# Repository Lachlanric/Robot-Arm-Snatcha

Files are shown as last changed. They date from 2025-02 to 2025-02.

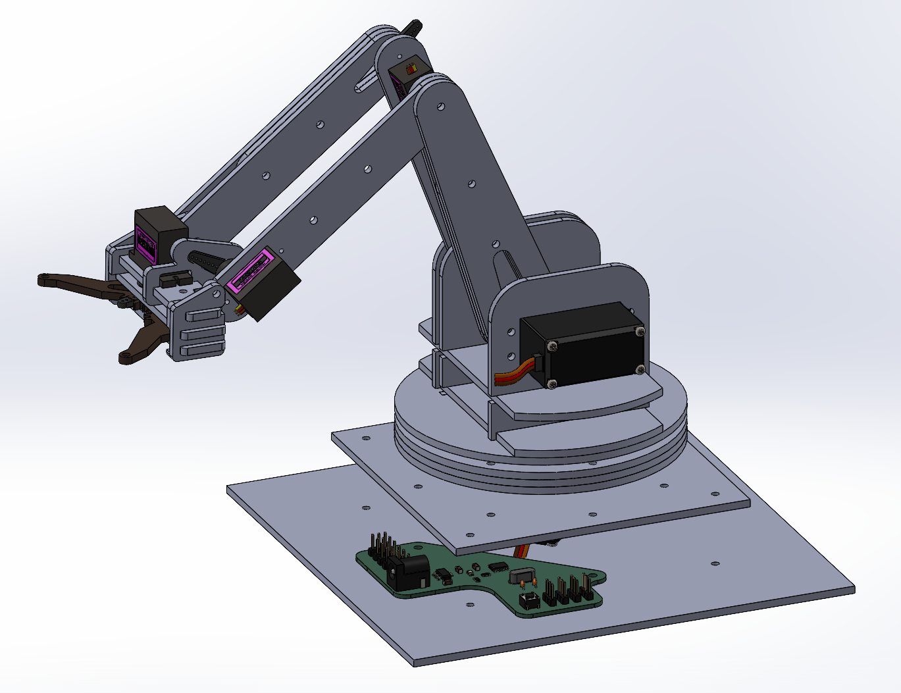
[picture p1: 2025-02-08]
Gallery/Solidworks.png

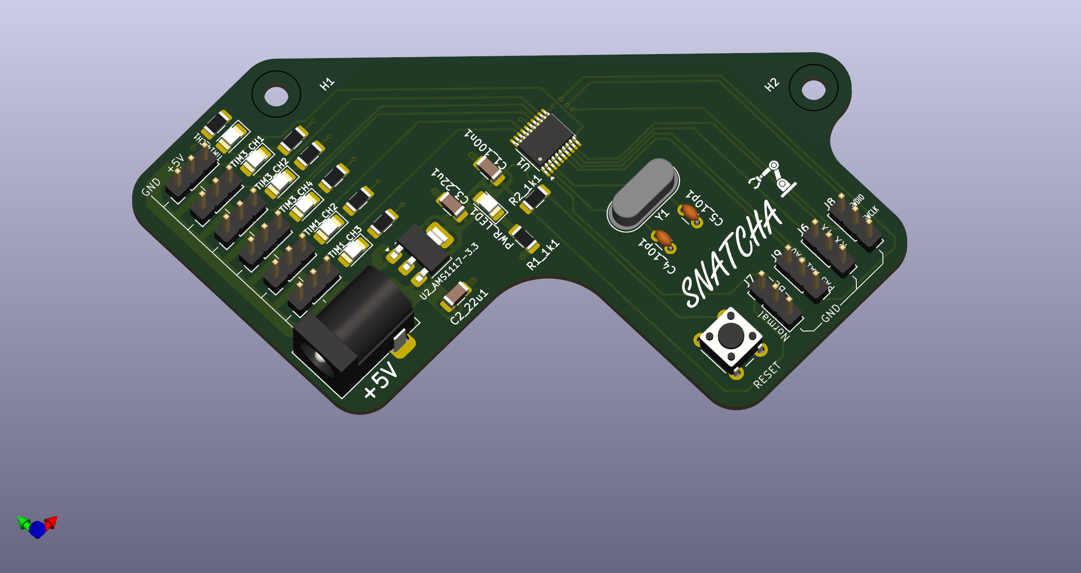
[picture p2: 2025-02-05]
Gallery/PCB.png

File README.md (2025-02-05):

# "Snatcha"

4-DoF Robotic Arm (excluding end effector) + Claw Gripper.

Entire robot (minus electronics) can be laser cut from 3mm wood or acrylic and fastened with M3 screws.

Can be controlled over UART communication (requires USB to UART converter) using either:
1. IK pose control python app `Operation/IK Control/app.py`
   
   OR
2. Oculus Quest 2 controller unity app `Operation/VR Control/Unity`

https://github.com/user-attachments/assets/1d7107a9-4986-4063-b4a9-3a9e8fb0a1fe

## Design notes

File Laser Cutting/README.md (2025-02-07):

# Laser cutting files

Cut in order of colours: Red > Cyan > Black.

Target material thickness: 3mm

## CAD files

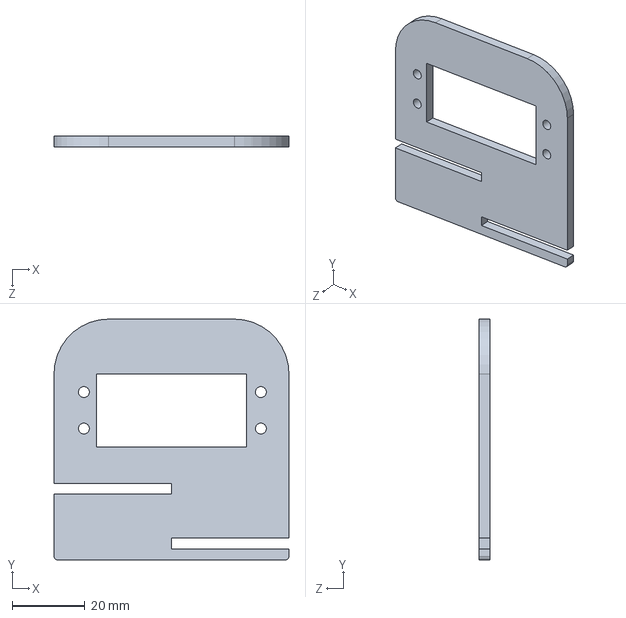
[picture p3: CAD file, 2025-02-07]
3D/SOLIDWORKS/BaseMotorSlot.SLDPRT
64.4 x 66.0 x 3.00 mm

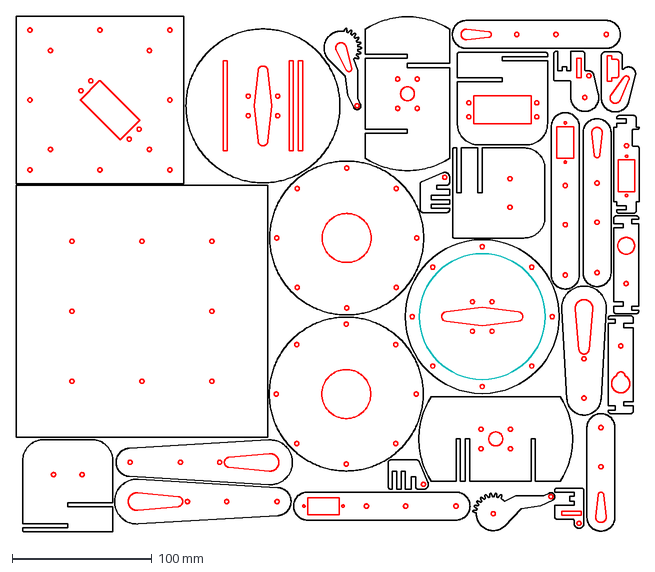
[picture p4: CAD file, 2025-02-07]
Laser Cutting/laser_cutting_colour.dxf
445.2 x 368.7 mm

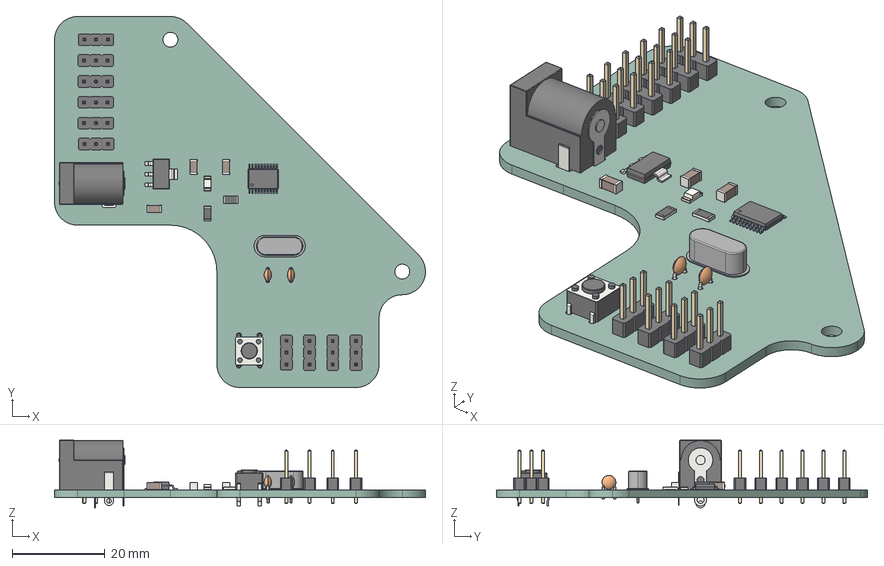
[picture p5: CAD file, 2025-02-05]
PCB/KiCad/STM32F070F6P6-Robot-Arm-2/STM32F070F6P6-Robot-Arm-2.step
80.0 x 80.0 x 14.6 mm
PinHeader_1x03_P254mm_Vertical x 10
BarrelJack_Horizontal
Crystal_HC49-4H_Vertical
R_1206_3216Metric x 2
C_1206_3216Metric x 3
LED_1206_3216Metric
C_Disc_D30mm_W16mm_P250mm x 2
SW_PUSH_6mm
SOT_223
TSSOP_20_44x65mm_P065mm
STM32F070F6P6-Robot-Arm-2_PCB

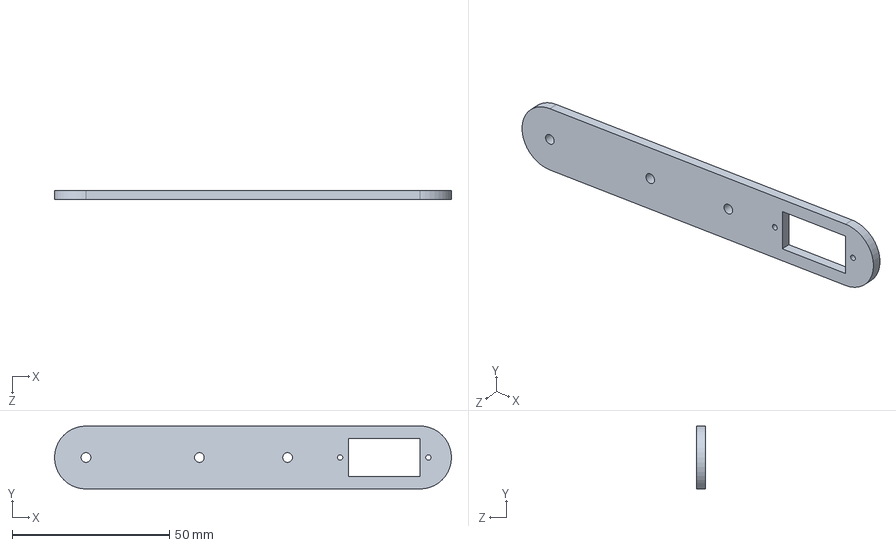
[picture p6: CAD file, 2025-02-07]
3D/SOLIDWORKS/L1_body - motor mount.SLDPRT
126.0 x 20.0 x 3.00 mm

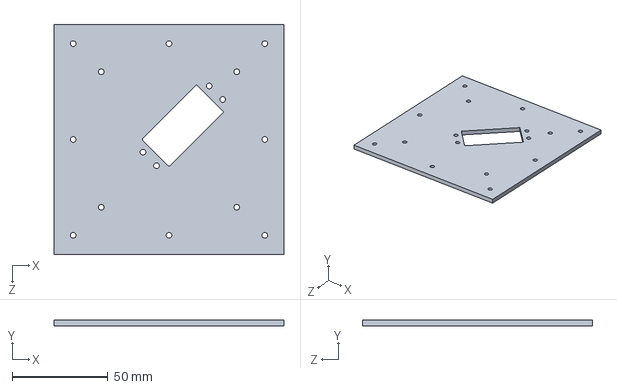
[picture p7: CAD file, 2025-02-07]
3D/SOLIDWORKS/BaseSquare.SLDPRT
120.0 x 3.00 x 120.0 mm

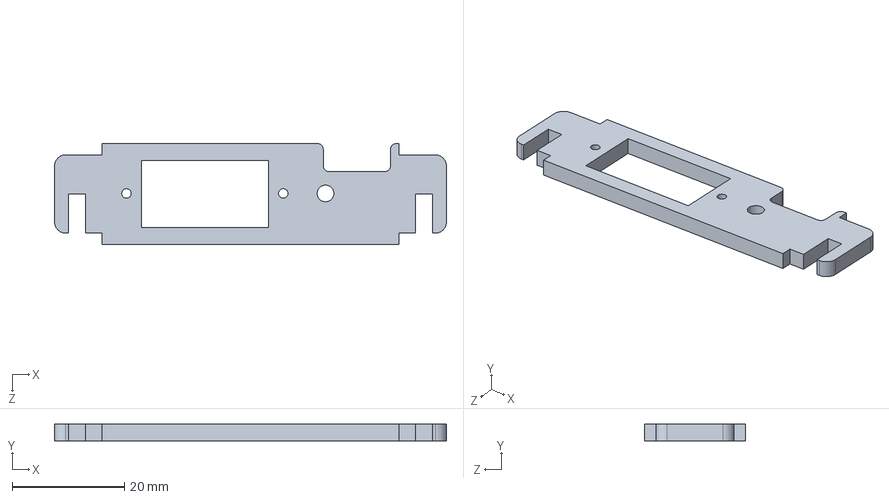
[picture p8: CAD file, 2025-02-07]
3D/SOLIDWORKS/Claw_MotorSlot.SLDPRT
70.0 x 3.00 x 18.0 mm

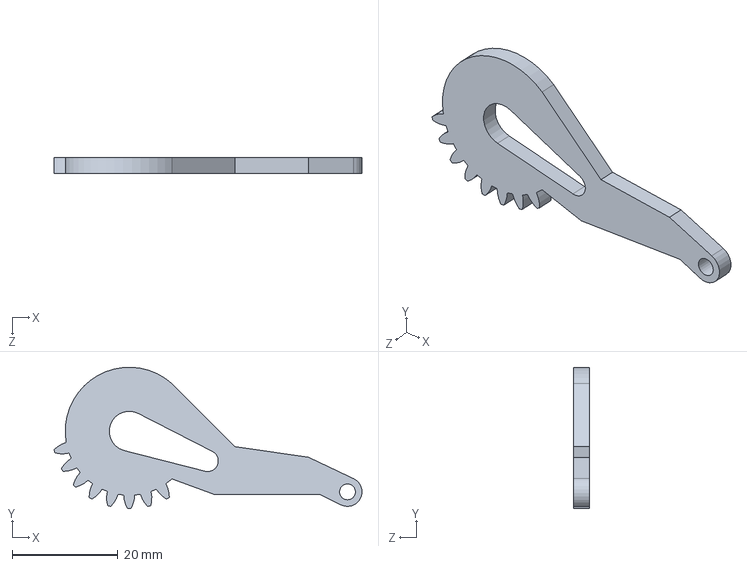
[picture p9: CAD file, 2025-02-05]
3D/SOLIDWORKS/Gear1.SLDPRT
58.2 x 26.7 x 3.00 mm

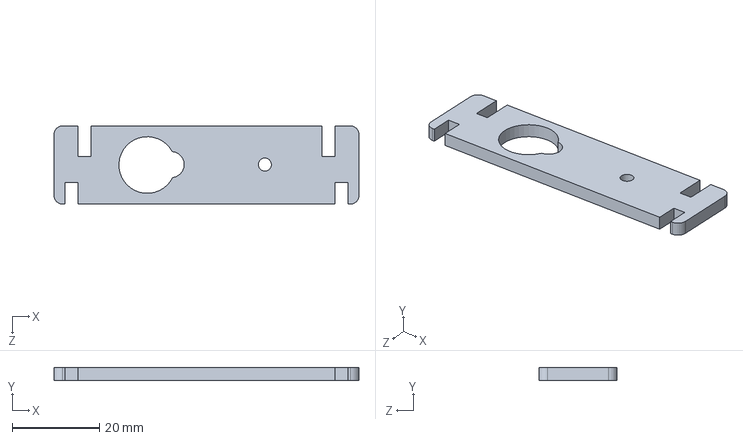
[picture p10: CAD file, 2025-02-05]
3D/SOLIDWORKS/Claw_GearSlot.SLDPRT
70.0 x 3.00 x 18.0 mm

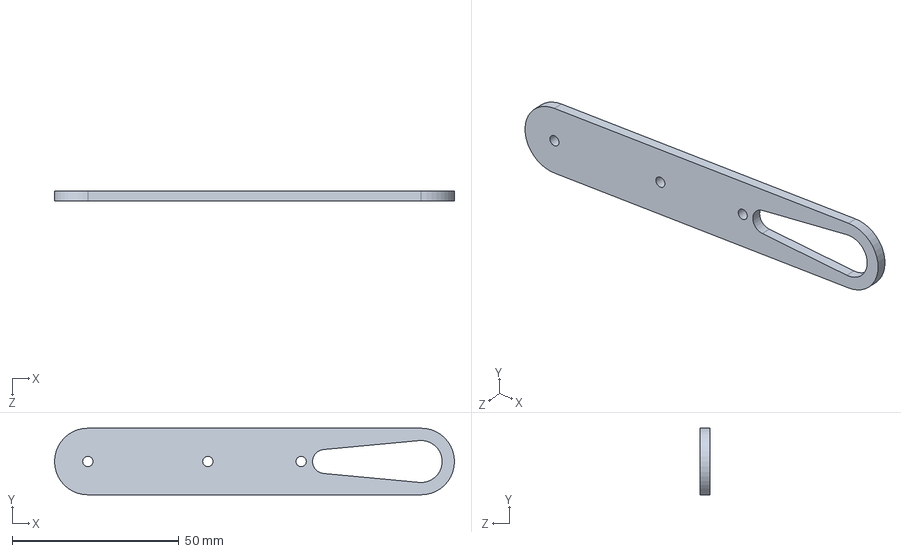
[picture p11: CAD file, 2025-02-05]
3D/SOLIDWORKS/L1_body - mg995r.SLDPRT
120.0 x 20.0 x 3.00 mm

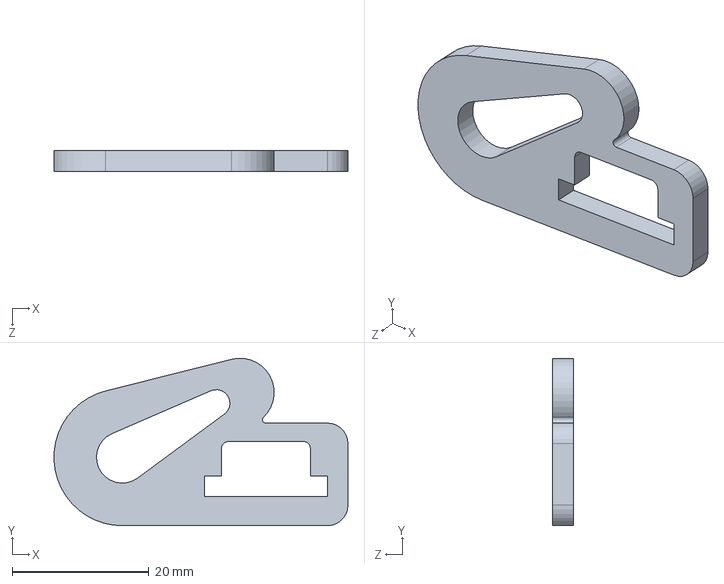
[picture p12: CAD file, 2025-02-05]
3D/SOLIDWORKS/Claw_SidePanel_Short.SLDPRT
43.0 x 24.5 x 3.00 mm

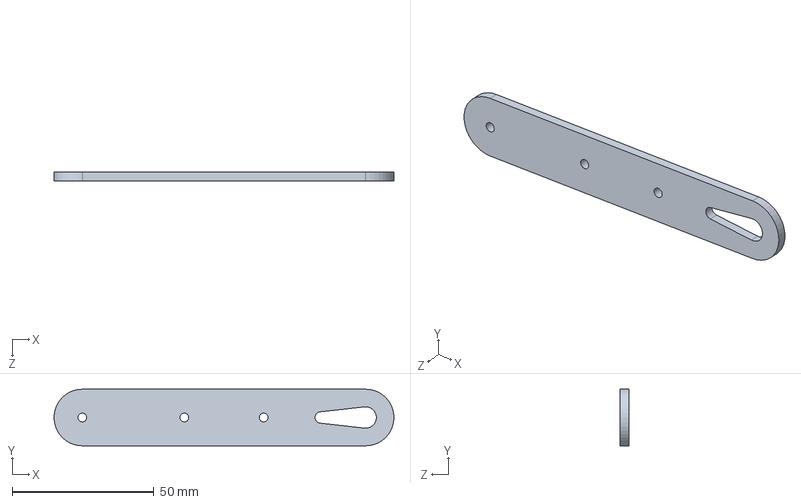
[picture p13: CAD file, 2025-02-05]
3D/SOLIDWORKS/L1_body.SLDPRT
120.0 x 20.0 x 3.00 mm

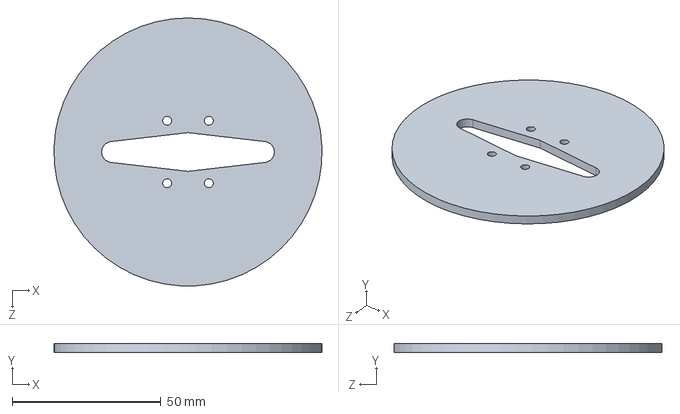
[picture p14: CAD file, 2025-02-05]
3D/SOLIDWORKS/CircleBase-InnerBottom.SLDPRT
90.0 x 3.00 x 90.0 mm

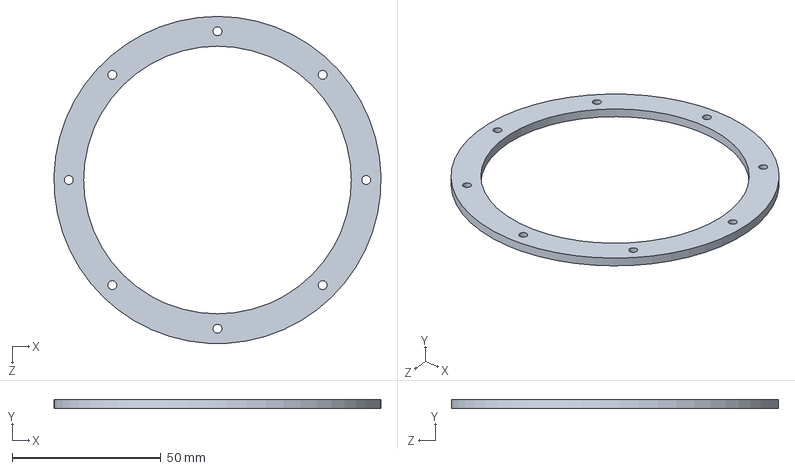
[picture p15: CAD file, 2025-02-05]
3D/SOLIDWORKS/CircleBase-OuterBottom - 2.SLDPRT
110.0 x 3.00 x 110.0 mm

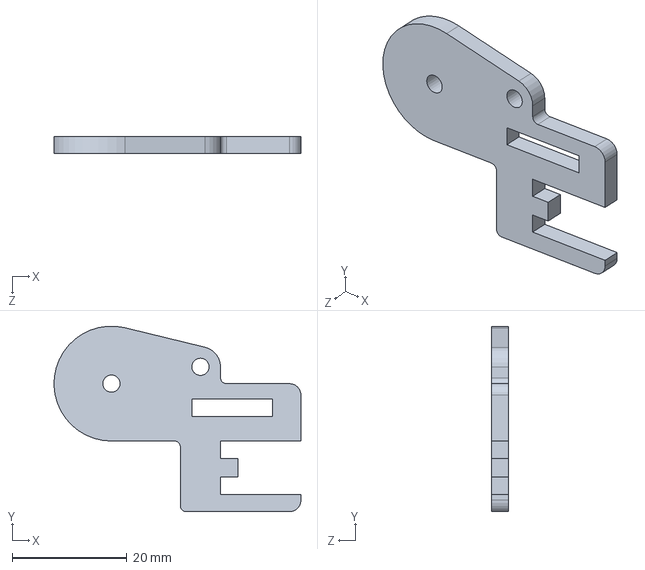
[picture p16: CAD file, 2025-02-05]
3D/SOLIDWORKS/Claw_SidePanel.SLDPRT
43.0 x 32.3 x 3.00 mm

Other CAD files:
3D/SOLIDWORKS/Assem1.SLDASM
3D/SOLIDWORKS/Claw_SidePanel_Shorter - Lock.SLDPRT
3D/SOLIDWORKS/BaseSquare - larger_2.SLDPRT
3D/SOLIDWORKS/BaseHorizontalSlots.SLDPRT
3D/SOLIDWORKS/BaseHorizontalSlots_LastInsert.SLDPRT
3D/SOLIDWORKS/BaseMotorSlot_SingleHole.SLDPRT
3D/SOLIDWORKS/BaseMotorSlot_SingleHole_LastInsert.SLDPRT
3D/SOLIDWORKS/CircleBase - UnderHorn.SLDPRT
3D/SOLIDWORKS/CircleBase-InnerTop - 3.SLDPRT
3D/SOLIDWORKS/Claw_Bottom_2.SLDPRT
3D/SOLIDWORKS/Claw_SidePanel - old.SLDPRT
3D/SOLIDWORKS/Claw_SidePanel_Shorter.SLDPRT
3D/SOLIDWORKS/Gear2.SLDPRT
3D/SOLIDWORKS/L1_body - middle spacing - mg995r taperred.SLDPRT
3D/SOLIDWORKS/L1_body - middle spacing.SLDPRT
3D/SOLIDWORKS/L1_body_taper.SLDPRT
3D/SOLIDWORKS/M90S.SLDPRT
3D/SOLIDWORKS/MG90S_horn1.SLDPRT
3D/SOLIDWORKS/MG995_large.SLDPRT

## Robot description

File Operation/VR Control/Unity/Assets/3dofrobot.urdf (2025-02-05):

<?xml version="1.0" ?>
<robot name="3dof_robot_arm">
  <!-- Base Link -->
  <link name="base_link">
    <visual>
      <geometry>
        <cylinder radius="0.1" length="0.2"/>
      </geometry>
      <origin xyz="0 0 0.1" rpy="0 0 0"/>
      <material name="grey">
        <color rgba="0.5 0.5 0.5 1"/>
      </material>
    </visual>
  </link>

  <!-- Link 1 -->
  <link name="link_1">
    <visual>
      <geometry>
        <cylinder radius="0.05" length="0.4"/>
      </geometry>
      <origin xyz="0 0 0.2" rpy="0 0 0"/>
      <material name="blue">
        <color rgba="0.0 0.0 1.0 1"/>
      </material>
    </visual>
  </link>

  <!-- Link 2 -->
  <link name="link_2">
    <visual>
      <geometry>
        <cylinder radius="0.05" length="0.4"/>
      </geometry>
      <origin xyz="0 0 0.2" rpy="0 0 0"/>
      <material name="green">
        <color rgba="0.0 1.0 0.0 1"/>
      </material>
    </visual>
  </link>

  <!-- Link 3 -->
  <link name="link_3">
    <visual>
      <geometry>
        <cylinder radius="0.05" length="0.4"/>
      </geometry>
      <origin xyz="0 0 0.2" rpy="0 0 0"/>
      <material name="red">
        <color rgba="1.0 0.0 0.0 1"/>
      </material>
    </visual>
  </link>

  <!-- Joints -->
  <!-- Joint 1 -->
  <joint name="joint_1" type="revolute">
    <parent link="base_link"/>
    <child link="link_1"/>
    <origin xyz="0 0 0.2" rpy="0 0 0"/>
    <axis xyz="0 0 1"/>
    <limit lower="-3.14" upper="3.14" effort="10" velocity="1.0"/>
  </joint>

  <!-- Joint 2 -->
  <joint name="joint_2" type="revolute">
    <parent link="link_1"/>
    <child link="link_2"/>
    <origin xyz="0 0 0.4" rpy="0 0 0"/>
    <axis xyz="0 1 0"/>
    <limit lower="-1.57" upper="1.57" effort="10" velocity="1.0"/>
  </joint>

  <!-- Joint 3 -->
  <joint name="joint_3" type="revolute">
    <parent link="link_2"/>
    <child link="link_3"/>
    <origin xyz="0 0 0.4" rpy="0 0 0"/>
    <axis xyz="1 0 0"/>
    <limit lower="-1.57" upper="1.57" effort="10" velocity="1.0"/>
  </joint>
</robot>

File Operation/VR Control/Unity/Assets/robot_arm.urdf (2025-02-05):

<?xml version="1.0"?>
<robot name="robot_arm">

  <!-- Base Link -->
  <link name="base">
    <visual>
      <geometry>
        <cylinder radius="0.05" length="0.1"/>
      </geometry>
      <origin xyz="0 0 0" rpy="0 0 0"/>
      <material name="gray">
        <color rgba="0.5 0.5 0.5 1.0"/>
      </material>
    </visual>
  </link>

  <!-- Link 1 -->
  <link name="L1">
    <visual>
      <geometry>
        <cylinder radius="0.02" length="0.1"/>
      </geometry>
      <origin xyz="0 0 0.05" rpy="0 0 0"/>
      <material name="blue">
        <color rgba="0.0 0.0 1.0 1.0"/>
      </material>
    </visual>
  </link>

  <!-- Link 2 -->
  <link name="L2">
    <visual>
      <geometry>
        <cylinder radius="0.02" length="0.1"/>
      </geometry>
      <origin xyz="0 0 0.05" rpy="0 0 0"/>
      <material name="green">
        <color rgba="0.0 1.0 0.0 1.0"/>
      </material>
    </visual>
  </link>

  <!-- End Effector -->
  <link name="end_effector">
    <visual>
      <geometry>
        <sphere radius="0.03"/>
      </geometry>
      <origin xyz="0 0 0" rpy="0 0 0"/>
      <material name="red">
        <color rgba="1.0 0.0 0.0 1.0"/>
      </material>
    </visual>
  </link>

  <!-- Base to L1 Joint -->
  <joint name="base_to_L1" type="revolute">
    <parent link="base"/>
    <child link="L1"/>
    <origin xyz="0 0 0.05" rpy="0 0 0"/>
    <axis xyz="0 0 1"/>
    <limit lower="-3.14159" upper="3.14159" effort="10" velocity="1"/>
  </joint>

  <!-- L1 to L2 Joint -->
  <joint name="L1_to_L2" type="revolute">
    <parent link="L1"/>
    <child link="L2"/>
    <origin xyz="0 0 0.1" rpy="0 0 0"/>
    <axis xyz="0 1 0"/>
    <limit lower="-3.14159" upper="3.14159" effort="10" velocity="1"/>
  </joint>

  <!-- L2 to End Effector Joint -->
  <joint name="L2_to_end_effector" type="revolute">
    <parent link="L2"/>
    <child link="end_effector"/>
    <origin xyz="0 0 0.1" rpy="0 0 0"/>
    <axis xyz="0 1 0"/>
    <limit lower="-3.14159" upper="3.14159" effort="10" velocity="1"/>
  </joint>

</robot>

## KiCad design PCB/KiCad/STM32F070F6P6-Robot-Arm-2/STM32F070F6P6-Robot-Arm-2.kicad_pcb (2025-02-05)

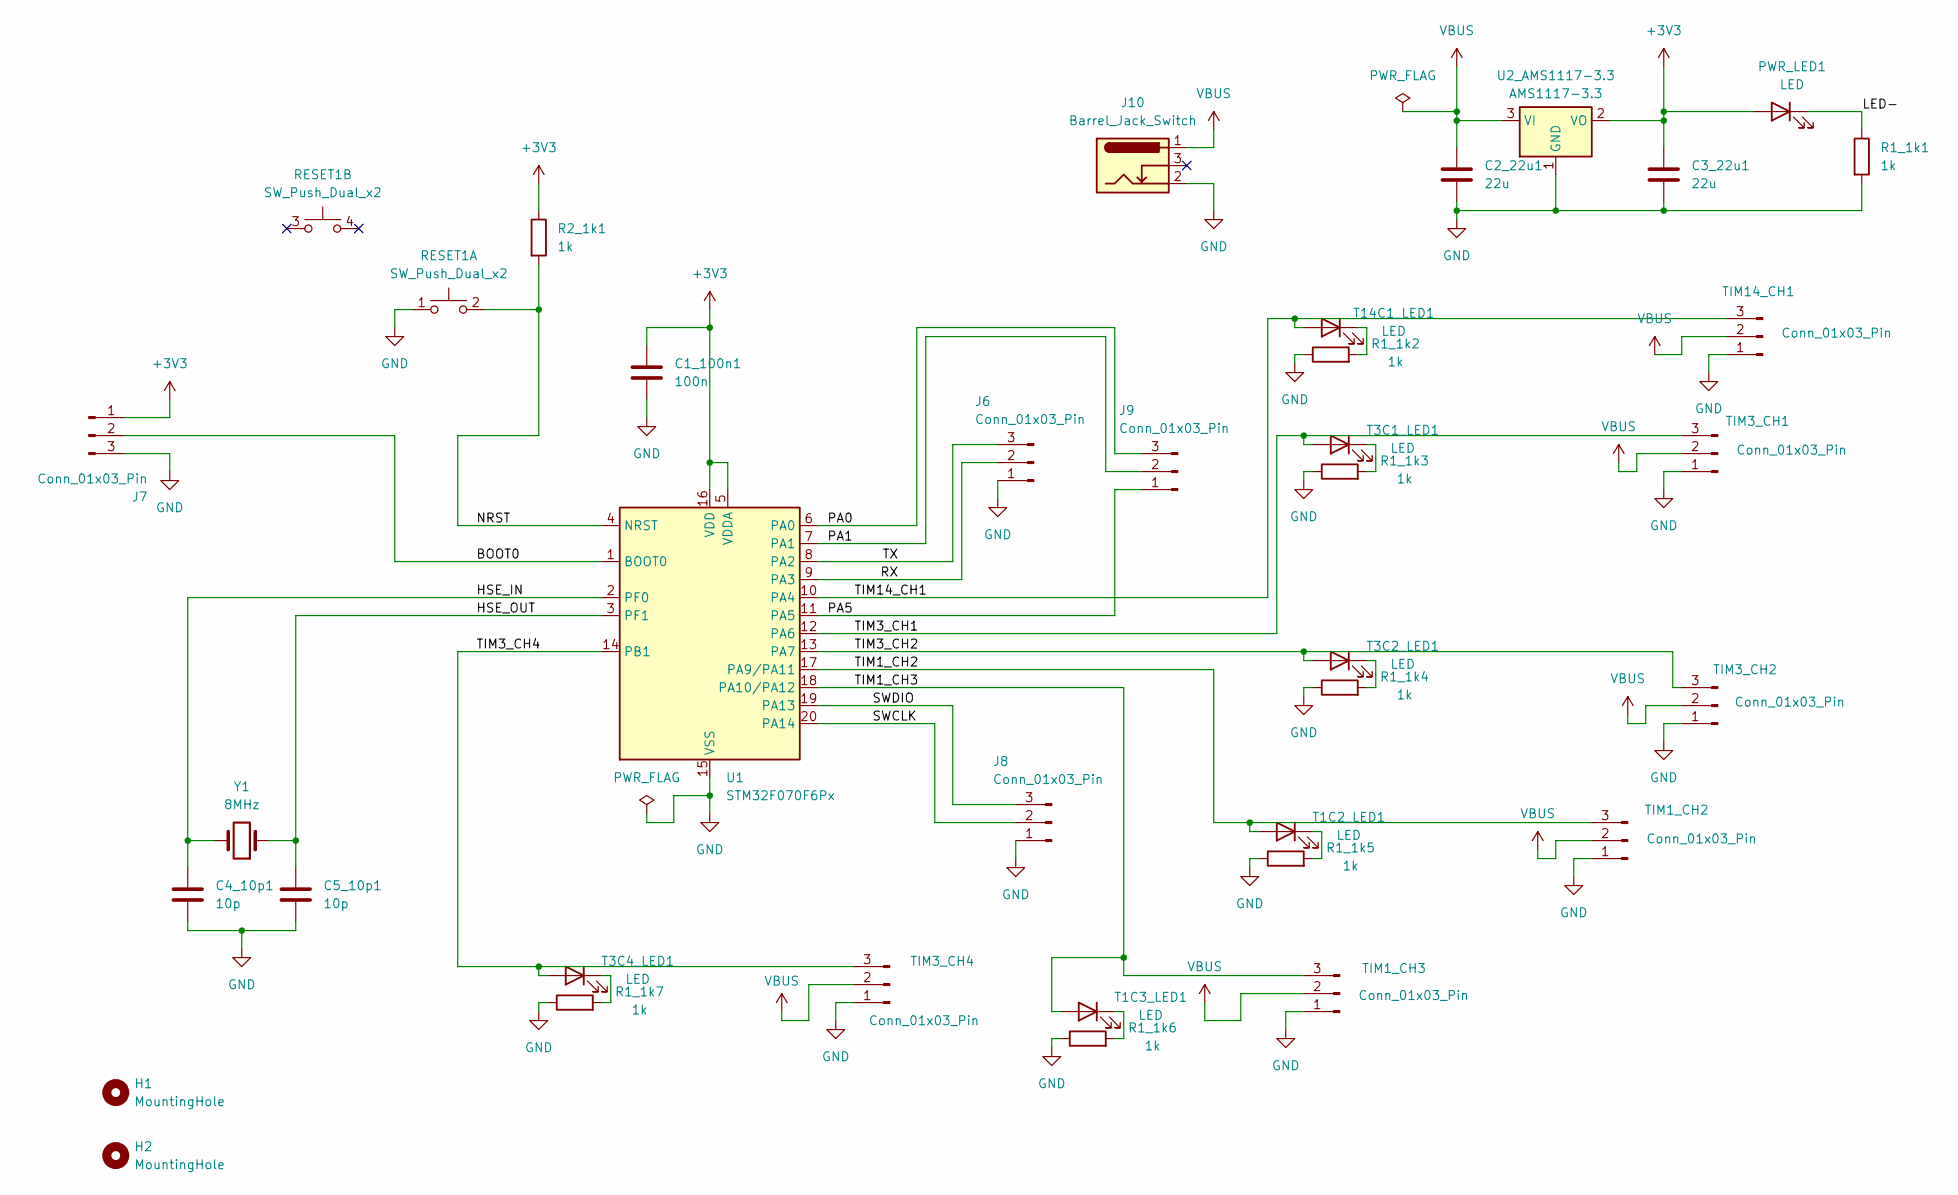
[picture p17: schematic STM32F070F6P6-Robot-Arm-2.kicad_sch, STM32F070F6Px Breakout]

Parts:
C1_100n1: 100n; C_1206_3216Metric_Pad1.33x1.80mm_HandSolder
C2_22u1, C3_22u1: 22u; C_1206_3216Metric_Pad1.33x1.80mm_HandSolder
C4_10p1, C5_10p1: 10p; C_Disc_D3.0mm_W1.6mm_P2.50mm
H1, H2: MountingHole; MountingHole_3.2mm_M3
J6, J7, J8, J9: Conn_01x03_Pin; PinHeader_1x03_P2.54mm_Vertical
J10: Barrel_Jack_Switch; BarrelJack_Horizontal
PWR_LED1: LED; LED_1206_3216Metric_Pad1.42x1.75mm_HandSolder
R1_1k1, R1_1k2, R1_1k3, R1_1k4, R1_1k5, R1_1k6, R1_1k7, R2_1k1: 1k; R_1206_3216Metric_Pad1.30x1.75mm_HandSolder
RESET1: SW_Push_Dual_x2; SW_PUSH_6mm
T1C2_LED1, T1C3_LED1, T3C1_LED1, T3C2_LED1, T3C4_LED1, T14C1_LED1: LED; LED_1206_3216Metric_Pad1.42x1.75mm_HandSolder
TIM1_CH2, TIM1_CH3, TIM3_CH1, TIM3_CH2, TIM3_CH4, TIM14_CH1: Conn_01x03_Pin; PinHeader_1x03_P2.54mm_Vertical
U1: STM32F070F6Px; TSSOP-20_4.4x6.5mm_P0.65mm
U2_AMS1117-3.3: AMS1117-3.3; SOT-223-3_TabPin2
Y1: 8MHz; Crystal_HC49-4H_Vertical

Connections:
+3V3: C1_100n1.1, C3_22u1.1, J7.1, PWR_LED1.2 (A), R2_1k1.1, U1.5 (VDDA), U1.16 (VDD), U2_AMS1117-3.3.2 (VO)
/BOOT0: J7.2, U1.1 (BOOT0)
/HSE_IN: C4_10p1.1, U1.2 (PF0), Y1.2
/HSE_OUT: C5_10p1.1, U1.3 (PF1), Y1.1
/LED-: PWR_LED1.1 (K), R1_1k1.1
/NRST: R2_1k1.2, RESET1.2 (D), U1.4 (NRST)
/PA0: J9.3, U1.6 (PA0)
/PA1: J9.2, U1.7 (PA1)
/PA5: J9.1, U1.11 (PA5)
/RX: J6.2, U1.9 (PA3)
/SWCLK: J8.2, U1.20 (PA14)
/SWDIO: J8.3, U1.19 (PA13)
/TIM1_CH2: T1C2_LED1.2 (A), TIM1_CH2.3, U1.17 (PA9/PA11)
/TIM1_CH3: T1C3_LED1.2 (A), TIM1_CH3.3, U1.18 (PA10/PA12)
/TIM3_CH1: T3C1_LED1.2 (A), TIM3_CH1.3, U1.12 (PA6)
/TIM3_CH2: T3C2_LED1.2 (A), TIM3_CH2.3, U1.13 (PA7)
/TIM3_CH4: T3C4_LED1.2 (A), TIM3_CH4.3, U1.14 (PB1)
/TIM14_CH1: T14C1_LED1.2 (A), TIM14_CH1.3, U1.10 (PA4)
/TX: J6.3, U1.8 (PA2)
GND: C1_100n1.2, C2_22u1.2, C3_22u1.2, C4_10p1.2, C5_10p1.2, J6.1, J7.3, J8.1, J10.2, R1_1k1.2, R1_1k2.1, R1_1k3.1, R1_1k4.1, R1_1k5.1, R1_1k6.1, R1_1k7.1, RESET1.1 (C), TIM1_CH2.1, TIM1_CH3.1, TIM3_CH1.1, TIM3_CH2.1, TIM3_CH4.1, TIM14_CH1.1, U1.15 (VSS), U2_AMS1117-3.3.1 (GND)
unnamed: R1_1k5.2, T1C2_LED1.1 (K)
unnamed: R1_1k6.2, T1C3_LED1.1 (K)
unnamed: R1_1k3.2, T3C1_LED1.1 (K)
unnamed: R1_1k4.2, T3C2_LED1.1 (K)
unnamed: R1_1k7.2, T3C4_LED1.1 (K)
unnamed: R1_1k2.2, T14C1_LED1.1 (K)
VBUS: C2_22u1.1, J10.1, TIM1_CH2.2, TIM1_CH3.2, TIM3_CH1.2, TIM3_CH2.2, TIM3_CH4.2, TIM14_CH1.2, U2_AMS1117-3.3.3 (VI)

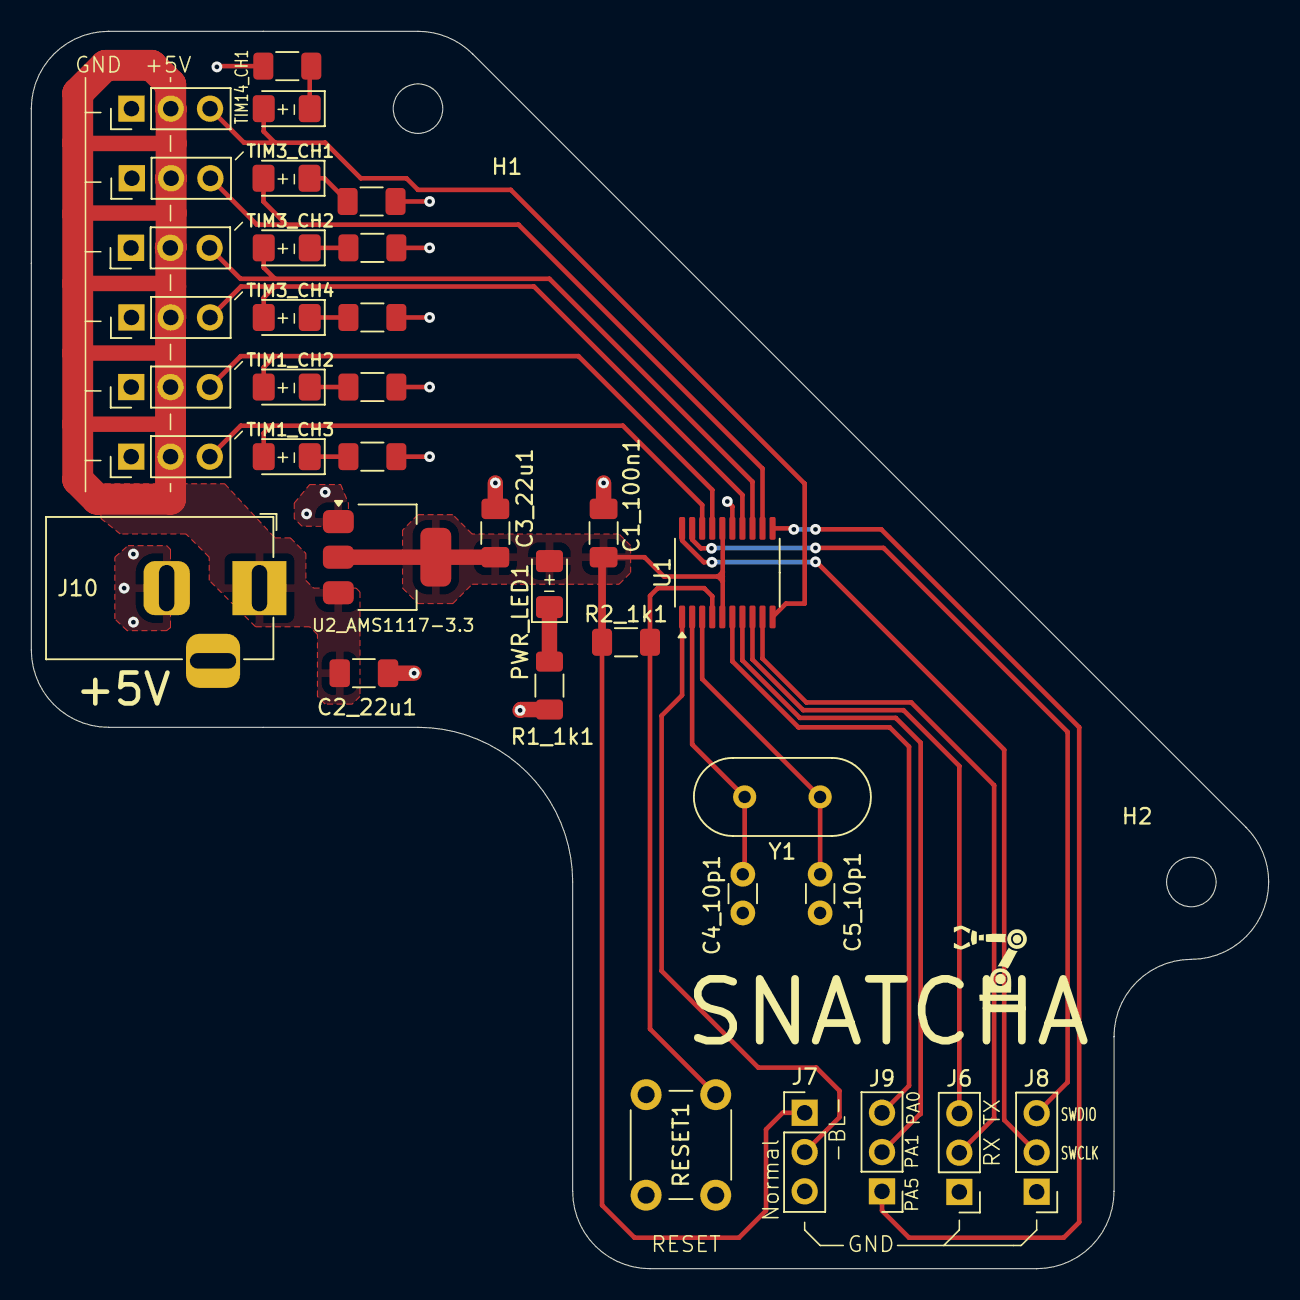
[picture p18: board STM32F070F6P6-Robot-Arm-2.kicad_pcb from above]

Board: 2 copper layers, 80.0 x 80.0 mm, 37 parts (0 on the bottom side), 27 nets.

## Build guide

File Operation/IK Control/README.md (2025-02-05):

# Python app using TKinter to control robot pose using XYZ coordinates, as well as wrist and claw actions.

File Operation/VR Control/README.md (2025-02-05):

# Unity app to control robot pose and claw action using Oculus Quest 2 controller.

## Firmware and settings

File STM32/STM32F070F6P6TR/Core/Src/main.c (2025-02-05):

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
/* Includes ------------------------------------------------------------------*/
#include "main.h"

/* USER CODE BEGIN Includes */

#include <string.h>
#include <stdio.h>
#include <stdlib.h>

/* USER CODE END Includes */

TIM_HandleTypeDef htim1;
TIM_HandleTypeDef htim3;
TIM_HandleTypeDef htim14;

UART_HandleTypeDef huart2;
DMA_HandleTypeDef hdma_usart2_rx;

void SystemClock_Config(void);
static void MX_GPIO_Init(void);
static void MX_DMA_Init(void);
static void MX_USART2_UART_Init(void);
static void MX_TIM3_Init(void);
static void MX_TIM1_Init(void);
static void MX_TIM14_Init(void);
/* USER CODE BEGIN 0 */

#define max(X, Y) (((X) < (Y)) ? (Y) : (X))
#define min(X, Y) (((X) > (Y)) ? (Y) : (X))

#define UART2_rxBuffer_size 16
uint8_t UART2_rxBuffer[UART2_rxBuffer_size];

#define numMotors 5

uint8_t motorInFocus = 0;
float desiredMotorAngles[numMotors];
float currentMotorAngles[numMotors];
float currentMotorVelocities[numMotors];

// ORIGINAL 180 - 1050
#define motorLoBase 540
#define motorHiBase 3150
const float motorRangeBase = motorHiBase - motorLoBase;

float motorLo[numMotors] = {
		motorLoBase + motorRangeBase*27/255,
		motorLoBase + motorRangeBase*29/255,
		motorLoBase + motorRangeBase*3/255,
		motorLoBase,
		motorLoBase + motorRangeBase*74/255
};

float motorHi[numMotors] = {
		motorHiBase,
		motorLoBase + motorRangeBase*195/255,
		motorLoBase + motorRangeBase*245/255,
		motorHiBase,
		motorLoBase + motorRangeBase*160/255
};

float motorMaxVel[numMotors] = { 10, 8, 5, 20, 50};
float motorVelIncr[numMotors] = { 0.03, 0.03, 0.03, 0.06, 0.50};

float velIncrBase = 0.03, velBase = 0.1;



void updateMotorAngles() {
	TIM3->CCR1 = currentMotorAngles[0];
	TIM3->CCR2 = currentMotorAngles[1];
	TIM3->CCR4 = currentMotorAngles[2];
	TIM14->CCR1 = currentMotorAngles[3];
	TIM1->CCR2 = currentMotorAngles[4];
}

void moveMotorAngles() {
	for(int i=0; i<numMotors; i++) {
		currentMotorAngles[i] += currentMotorVelocities[i];
	}
}


float newVelocity(int32_t motorIdx) {

	float a = 300, b = motorMaxVel[motorIdx];
	float dist = desiredMotorAngles[motorIdx] - currentMotorAngles[motorIdx];

	// Close enough, snap to angle
	if (abs(dist) < 1) {
		currentMotorAngles[motorIdx] = desiredMotorAngles[motorIdx];
		return 0;
	}


	if (dist > 0) {

		return max(velBase, min( currentMotorVelocities[motorIdx] + motorVelIncr[motorIdx], (min(b, b*dist/a)) ) );

	} else if (dist < 0) {
		return min(-velBase, max( currentMotorVelocities[motorIdx] - motorVelIncr[motorIdx], - (min(b, b*(-dist)/a)) ) );

	}
	return 0;

}


void approachMotorAngles() {

	for(int i=0; i<numMotors; i++) {
		currentMotorVelocities[i] = newVelocity(i);
	}
	moveMotorAngles();
	updateMotorAngles();
}

/* USER CODE END 0 */

/**
  * @brief  The application entry point.
  * @retval int
  */
int main(void)
{

  /* MCU Configuration--------------------------------------------------------*/

  /* Reset of all peripherals, Initializes the Flash interface and the Systick. */
  HAL_Init();

  /* Configure the system clock */
  SystemClock_Config();

  /* Initialize all configured peripherals */
  MX_GPIO_Init();
  MX_DMA_Init();
  MX_USART2_UART_Init();
  MX_TIM3_Init();
  MX_TIM1_Init();
  MX_TIM14_Init();
  /* USER CODE BEGIN 2 */


  // Init motor positions
  TIM3->ARR = 60000;	// 12MHz / 10 (prescaler) / 60000 (ARR) = 20 Hz
  TIM14->ARR = 60000;	// 12MHz / 10 (prescaler) / 60000 (ARR) = 20 Hz
  TIM1->ARR = 60000;	// 12MHz / 10 (prescaler) / 60000 (ARR) = 20 Hz
  for(int i=0; i<numMotors; i++) {
	  desiredMotorAngles[i] = (motorLo[i] + motorHi[i]) / 2.0;
	  currentMotorAngles[i] = desiredMotorAngles[i];
	  currentMotorVelocities[i] = 0;
  }
  updateMotorAngles();

  HAL_TIM_PWM_Start(&htim3, TIM_CHANNEL_1);
  HAL_TIM_PWM_Start(&htim3, TIM_CHANNEL_2);
  HAL_TIM_PWM_Start(&htim3, TIM_CHANNEL_4);
  HAL_TIM_PWM_Start(&htim14, TIM_CHANNEL_1);
  HAL_TIM_PWM_Start(&htim1, TIM_CHANNEL_2);

  HAL_UART_Receive_DMA(&huart2, UART2_rxBuffer, numMotors);

  /* USER CODE END 2 */

  /* Infinite loop */
  /* USER CODE BEGIN WHILE */
  while (1)
  {
	  HAL_Delay(1);
	  approachMotorAngles();

    /* USER CODE END WHILE */

    /* USER CODE BEGIN 3 */

  }
  /* USER CODE END 3 */
}

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
/* USER CODE BEGIN 4 */


//uint8_t out_buff_2[128] = "Button received.\n\r";


void HAL_UART_RxCpltCallback(UART_HandleTypeDef *huart)
{

	for(int i=0; i<numMotors; i++) {
		float value = (float)(UART2_rxBuffer[i]) / 255.0;
		desiredMotorAngles[i] = motorLo[i] + (motorHi[i]-motorLo[i])*value;
	}

	HAL_UART_Receive_DMA(&huart2, UART2_rxBuffer, numMotors);
}


/* USER CODE END 4 */
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


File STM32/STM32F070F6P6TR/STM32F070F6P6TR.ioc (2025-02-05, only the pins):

Mcu.UserName=STM32F070F6Px
PA1.Signal=GPIO_Output
PA10.Signal=S_TIM1_CH3
PA13.Signal=SYS_SWDIO
PA14.Signal=SYS_SWCLK
PA2.Signal=USART2_TX
PA3.Signal=USART2_RX
PA4.Signal=S_TIM14_CH1
PA6.Signal=S_TIM3_CH1
PA7.Signal=S_TIM3_CH2
PA9.Signal=S_TIM1_CH2
PB1.Signal=S_TIM3_CH4
PF0-OSC_IN.Signal=RCC_OSC_IN
PF1-OSC_OUT.Signal=RCC_OSC_OUT

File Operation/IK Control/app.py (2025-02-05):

import tkinter as tk
import serial
from math import sqrt, atan2, acos, pi, radians, degrees
from time import sleep

# Create the main application window
root = tk.Tk()
root.title("Tkinter Slider Example")

ser = serial.Serial(
    port='COM5',
    baudrate=115200,
    parity=serial.PARITY_NONE,
    stopbits=serial.STOPBITS_ONE,
    bytesize=serial.EIGHTBITS,
    timeout=0.1
)

motorAngleLerps = [
    [(90,74), (180,219)],
    [(0,20),  (90,184)],
    [(0,25),  (180,246)],
    [(0,92),  (90,215)],
    [(0,255),  (255,0)]
]

def angleToMotorVal(ang, motorIdx):

    x1,y1 = motorAngleLerps[motorIdx][0]
    x2,y2 = motorAngleLerps[motorIdx][1]
    m = (y2-y1)/(x2-x1)

    motorVal = y1 + m*(ang - x1)
    return motorVal


# y = height

def print_vals(dummy):
    motorVals = None
    try:
        motorVals = calculate_motor_vals()
        ser.write(bytes(motorVals))
        # for i,value in enumerate(motorVals):
        #     ser.write(bytes([i, int(value)]))


    except ValueError as e:
        print(e)
    finally:
        print(motorVals)
    

def calculate_motor_vals():

    X,Y,Z,W,C = slider_X.get(), slider_Y.get(), slider_Z.get(), radians(slider_W.get()), radians(slider_C.get())
    print(f"{X}, {Y}, {Z}, {W}")

    L = 10
    h = 10

    R = sqrt(X**2 + Z**2)
    print(f"R =     {R}")
    ang = atan2(Z,X)
    print(f"ang =   {ang}")

    q = sqrt(R**2 + (Y-h)**2)
    print(f"q =     {q}")
    alpha = atan2(Y-h,R)
    print(f"alpha = {alpha}")
    theta = acos(q/(2*L)) + alpha
    print(f"theta = {theta}")

    phi = pi - 2*(theta-alpha)
    print(f"phi =   {phi}")
    psi = -(theta-pi+phi) + W
    print(f"psi =   {psi}")
    print("\n")

    motorAngles = [phi, theta, ang, psi, C]  # in radians
    motorVals = [int(angleToMotorVal(degrees(val),i)) for i,val in enumerate(motorAngles)]

    print(motorAngles)
    print([degrees(m) for m in motorAngles])
    
    # Clamp wrist angle
    motorVals[3] = min(255,max(0,motorVals[3]))
    
    for val in motorVals:
        if val<0 or val>255:
            raise ValueError("Motor values out of range:",motorVals)
    
    return motorVals




l = tk.Label(root, text = "X")
l.pack()
slider_X = tk.Scale(
    root,
    from_=-20,          # Minimum value of the slider
    to=20,           # Maximum value of the slider
    orient="horizontal",  # Orientation of the slider
    length=500,       # Length of the slider in pixels
    command=print_vals
)
slider_X.pack(pady=10)
slider_X.set(10)

l = tk.Label(root, text = "Y")
l.pack()
slider_Y = tk.Scale(
    root,
    from_=0,          # Minimum value of the slider
    to=30,           # Maximum value of the slider
    orient="horizontal",  # Orientation of the slider
    length=500,       # Length of the slider in pixels
    command=print_vals
)
slider_Y.pack(pady=10)
slider_Y.set(10)

l = tk.Label(root, text = "Z")
l.pack()
slider_Z = tk.Scale(
    root,
    from_=0,          # Minimum value of the slider
    to=20,           # Maximum value of the slider
    orient="horizontal",  # Orientation of the slider
    length=500,       # Length of the slider in pixels
    command=print_vals
)
slider_Z.pack(pady=10)
slider_Z.set(10)

l = tk.Label(root, text = "Wrist Angle")
l.pack()
slider_W = tk.Scale(
    root,
    from_=-90,          # Minimum value of the slider
    to=90,           # Maximum value of the slider
    orient="horizontal",  # Orientation of the slider
    length=500,       # Length of the slider in pixels
    command=print_vals
)
slider_W.pack(pady=10)
slider_W.set(0)

l = tk.Label(root, text = "Claw")
l.pack()
slider_C = tk.Scale(
    root,
    from_=0,          # Minimum value of the slider
    to=255,           # Maximum value of the slider
    orient="horizontal",  # Orientation of the slider
    length=500,       # Length of the slider in pixels
    command=print_vals
)
slider_C.pack(pady=10)
slider_C.set(128)



# Start the server
if __name__ == '__main__':

    try:
        # Run the application
        root.mainloop()
    except KeyboardInterrupt:
        pass
    # finally:
    #     ser.close()

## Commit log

2025-02-05 Updated READMEs and folders
    [3dofrobot.urdf, arm_urdf.urdf, robot_arm.urdf]
2025-02-07 Added holes for motor screws. Added laser cutting files.
    [Assem1.SLDASM, BaseMotorSlot.SLDPRT, BaseSquare.SLDPRT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]
2025-02-07 Updated schematic
    [STM32F070F6P6-Robot-Arm-2.kicad_sch]

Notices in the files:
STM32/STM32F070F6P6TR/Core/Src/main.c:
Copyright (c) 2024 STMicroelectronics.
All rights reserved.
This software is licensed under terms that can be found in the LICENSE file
